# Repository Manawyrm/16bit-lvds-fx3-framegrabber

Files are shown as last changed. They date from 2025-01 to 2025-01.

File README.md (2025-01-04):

# Cypress FX3-based 16bit LVDS Framegrabber (Hardware repo)

Framegrabber PCB with FX3 SuperSpeed Explorer Kit
Framegrabber PCB next to SuperSpeed Explorer Kit

### Overview

The 16bit-LVDS-FX3-Framegrabber is a Cypress FX3-based PCB, which can digitize a parallel 16bit digital video stream from a commercial image sensor.
It exposes a USB 3.0 UVC ("webcam") device to the operating system.

Video signal is accepted on a 50pin SCSI-II connector as parallel LVDS.  
Required signals:
- DATA_VALID
- HSYNC
- VSYNC
- PIXCLK
- DATA0 through DATA15

The framegrabber follows the common industry standard pinout for 16bit digital LVDS video.

### Errata
None so far. Rev. A works well.

### Additional info 
[Firmware](https://github.com/Manawyrm/16bit-lvds-fx3-framegrabber-fw)

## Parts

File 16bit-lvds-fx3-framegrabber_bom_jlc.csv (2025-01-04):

Comment | Designator | Footprint | LCSC Part Number
2kV 1nF | C2 | C_1206_3216Metric | C9196
100n 16V | C22,C1,C3,C4,C5,C6,C7,C8,C9,C10,C11,C12,C13,C14,C15,C16,C17,C18,C19,C20,C21 | C_0402_1005Metric_Pad0.74x0.62mm_HandSolder | C1525
10uF 16V | C23,C24,C25 | CP_EIA-3216-10_Kemet-I | C7171
GPIFII_J7 | J1 | PinHeader_2x20_P2.54mm_Vertical | C50980
GPIFII_J6 | J2 | PinHeader_2x20_P2.54mm_Vertical | C50980
100k | R1 | R_1206_3216Metric | C17900
33R | R2,R3,R4,R5,R6,R7,R8,R9,R10,R11,R12,R13,R14,R15,R16,R17,R18,R19,R20,R21 | R_0402_1005Metric | C25105
5787082-5 | U1 | DSUB-TH_5787082-5 | C3119894
SN65LVDT2DBV | U2,U3,U4,U5,U6,U7,U8,U9,U10,U11,U12,U13,U14,U15,U16,U17,U18,U19,U20,U21 | SOT-23-5 | C130020
AMS1117-3.3 | U22 | SOT-223-3_TabPin2 | C6186

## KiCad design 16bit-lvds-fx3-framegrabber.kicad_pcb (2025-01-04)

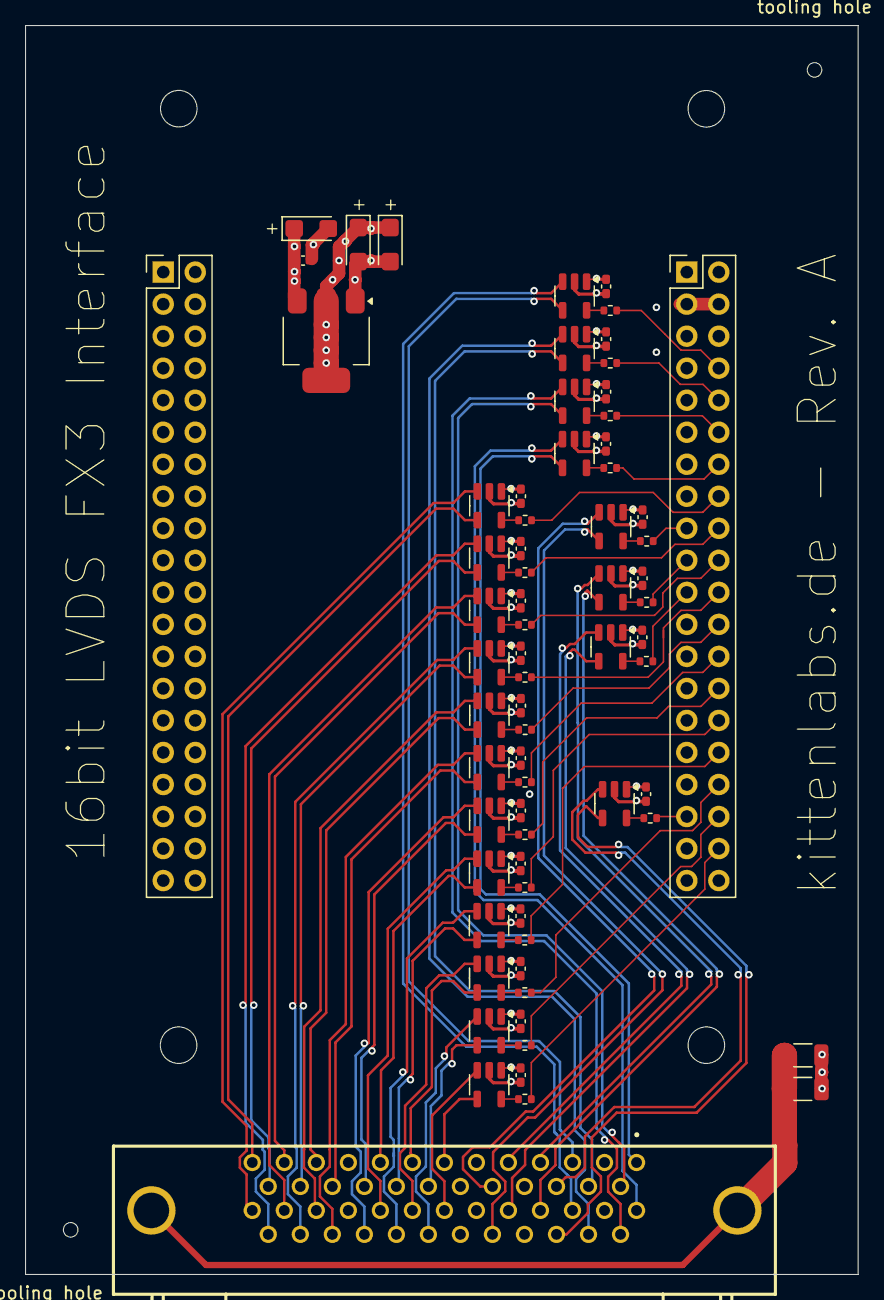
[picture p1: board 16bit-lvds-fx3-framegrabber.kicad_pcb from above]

Board: 4 copper layers, 66.0 x 99.1 mm, 72 parts (0 on the bottom side), 81 nets.

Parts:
C1, C3, C4, C5, C6, C7, C8, C9, C10, C11, C12, C13, C14, C15, C16, C17, C18, C19, C20, C21, C22: 100n 16V; C_0402_1005Metric_Pad0.74x0.62mm_HandSolder
C2: 2kV 1nF; C_1206_3216Metric
C23, C24, C25: 10uF 16V; CP_EIA-3216-10_Kemet-I
H1, H2: MountingHole; ToolingHole_JLCSMT
J1: GPIFII_J7; PinHeader_2x20_P2.54mm_Vertical
J2: GPIFII_J6; PinHeader_2x20_P2.54mm_Vertical
R1: 100k; R_1206_3216Metric
R2, R3, R4, R5, R6, R7, R8, R9, R10, R11, R12, R13, R14, R15, R16, R17, R18, R19, R20, R21: 33R; R_0402_1005Metric
U1: 5787082-5; DSUB-TH_5787082-5
U2, U3, U4, U5, U6, U7, U8, U9, U10, U11, U12, U13, U14, U15, U16, U17, U18, U19, U20, U21: SN65LVDT2DBV; SOT-23-5
U22: AMS1117-3.3; SOT-223-3_TabPin2

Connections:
+3V3: C1.1, C3.1, C4.1, C5.1, C6.1, C7.1, C8.1, C9.1, C10.1, C11.1, C12.1, C13.1, C14.1, C15.1, C16.1, C17.1, C18.1, C19.1, C20.1, C21.1, C23.1, C24.1, U2.1 (V_{CC}), U3.1 (V_{CC}), U4.1 (V_{CC}), U5.1 (V_{CC}), U6.1 (V_{CC}), U7.1 (V_{CC}), U8.1 (V_{CC}), U9.1 (V_{CC}), U10.1 (V_{CC}), U11.1 (V_{CC}), U12.1 (V_{CC}), U13.1 (V_{CC}), U14.1 (V_{CC}), U15.1 (V_{CC}), U16.1 (V_{CC}), U17.1 (V_{CC}), U18.1 (V_{CC}), U19.1 (V_{CC}), U20.1 (V_{CC}), U21.1 (V_{CC}), U22.2 (VO)
+5V: C22.1, C25.1, J2.3 (USB3_VBUS), J2.4 (USB3_VBUS), U22.3 (VI)
/DATA_VALID: J2.17 (CTL7), R20.2
/DATA_VALID+: U1.10, U20.3 (A)
/DATA_VALID-: U1.35, U20.4 (B)
/HSYNC: J2.19 (CTL6), R18.2
/HSYNC+: U1.7, U18.3 (A)
/HSYNC-: U1.32, U18.4 (B)
/OUT0: J2.38 (DQ0), R2.2
/OUT0+: U1.38, U2.3 (A)
/OUT0-: U1.13, U2.4 (B)
/OUT1: J2.36 (DQ1), R3.2
/OUT1+: U1.39, U3.3 (A)
/OUT1-: U1.14, U3.4 (B)
/OUT2: J2.34 (DQ2), R4.2
/OUT2+: U1.40, U4.3 (A)
/OUT2-: U1.15, U4.4 (B)
/OUT3: J2.32 (DQ3), R5.2
/OUT3+: U1.41, U5.3 (A)
/OUT3-: U1.16, U5.4 (B)
/OUT4: J2.30 (DQ4), R6.2
/OUT4+: U1.42, U6.3 (A)
/OUT4-: U1.17, U6.4 (B)
/OUT5: J2.28 (DQ5), R7.2
/OUT5+: U1.43, U7.3 (A)
/OUT5-: U1.18, U7.4 (B)
/OUT6: J2.26 (DQ6), R8.2
/OUT6+: U1.45, U8.3 (A)
/OUT6-: U1.20, U8.4 (B)
/OUT8: J2.22 (DQ8), R10.2
/OUT8+: U1.47, U10.3 (A)
/OUT8-: U1.22, U10.4 (B)
/OUT9: J2.20 (DQ9), R11.2
/OUT9+: U1.48, U11.3 (A)
/OUT9-: U1.23, U11.4 (B)
/OUT10: J2.18 (DQ10), R12.2
/OUT10+: U1.49, U12.3 (A)
/OUT10-: U1.24, U12.4 (B)
/OUT11: J2.16 (DQ11), R13.2
/OUT11+: U1.50, U13.3 (A)
/OUT11-: U1.25, U13.4 (B)
/OUT12: J2.14 (DQ12), R14.2
/OUT12+: U1.26, U14.3 (A)
/OUT12-: U1.1, U14.4 (B)
/OUT13: J2.12 (DQ13), R15.2
/OUT13+: U1.27, U15.3 (A)
/OUT13-: U1.2, U15.4 (B)
/OUT14: J2.10 (DQ14), R16.2
/OUT14+: U1.29, U16.3 (A)
/OUT14-: U1.4, U16.4 (B)
/OUT15: J2.8 (DQ15), R17.2
/OUT15+: U1.30, U17.3 (A)
/OUT15-: U1.5, U17.4 (B)
/PIXCLK: J2.35 (PCLK), R21.2
/PIXCLK+: U1.6, U21.3 (A)
/PIXCLK-: U1.31, U21.4 (B)
/VSYNC: J2.21 (CTL5), R19.2
/VSYNC+: U1.9, U19.3 (A)
/VSYNC-: U1.34, U19.4 (B)
GND: C1.2, C2.2, C3.2, C4.2, C5.2, C6.2, C7.2, C8.2, C9.2, C10.2, C11.2, C12.2, C13.2, C14.2, C15.2, C16.2, C17.2, C18.2, C19.2, C20.2, C21.2, C22.2, C23.2, C24.2, C25.2, J1.13 (GND), J1.15 (GND), J1.17 (GND), J1.25 (GND), J1.29 (GND), J1.39 (GND), J1.40 (GND), J2.6 (GND), J2.33 (GND), J2.37 (GND), R1.2, U1.3, U1.8, U1.19, U1.28, U1.33, U1.44, U2.2 (GND), U3.2 (GND), U4.2 (GND), U5.2 (GND), U6.2 (GND), U7.2 (GND), U8.2 (GND), U9.2 (GND), U10.2 (GND), U11.2 (GND), U12.2 (GND), U13.2 (GND), U14.2 (GND), U15.2 (GND), U16.2 (GND), U17.2 (GND), U18.2 (GND), U19.2 (GND), U20.2 (GND), U21.2 (GND), U22.1 (GND)
unnamed: C2.1, R1.1, U1.S1, U1.S2
unnamed: R2.1, U2.5 (R)
unnamed: R3.1, U3.5 (R)
unnamed: R4.1, U4.5 (R)
unnamed: R5.1, U5.5 (R)
unnamed: R6.1, U6.5 (R)
unnamed: R7.1, U7.5 (R)
unnamed: R8.1, U8.5 (R)
unnamed: R9.1, U9.5 (R)
unnamed: R10.1, U10.5 (R)
unnamed: R11.1, U11.5 (R)
unnamed: R12.1, U12.5 (R)
unnamed: R13.1, U13.5 (R)
unnamed: R14.1, U14.5 (R)
unnamed: R15.1, U15.5 (R)
unnamed: R16.1, U16.5 (R)
unnamed: R17.1, U17.5 (R)
unnamed: R18.1, U18.5 (R)
unnamed: R19.1, U19.5 (R)
unnamed: R20.1, U20.5 (R)
unnamed: R21.1, U21.5 (R)

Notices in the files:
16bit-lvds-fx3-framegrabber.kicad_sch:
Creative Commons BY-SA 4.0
